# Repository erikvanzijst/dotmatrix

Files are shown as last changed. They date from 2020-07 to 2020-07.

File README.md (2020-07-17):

16x16 Monochrome Dot Matrix Display
===================================

A project to design and create a custom LED matrix display.

Full writeup and details at: https://medium.com/@erikvanzijst/custom-16x16-matrix-display-pcb-96c40290c8bc

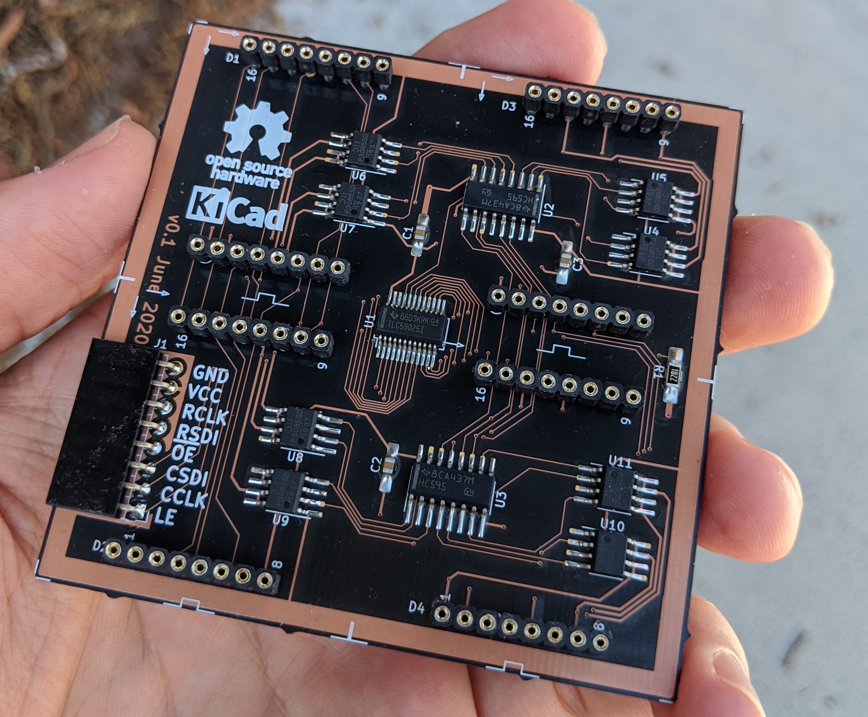
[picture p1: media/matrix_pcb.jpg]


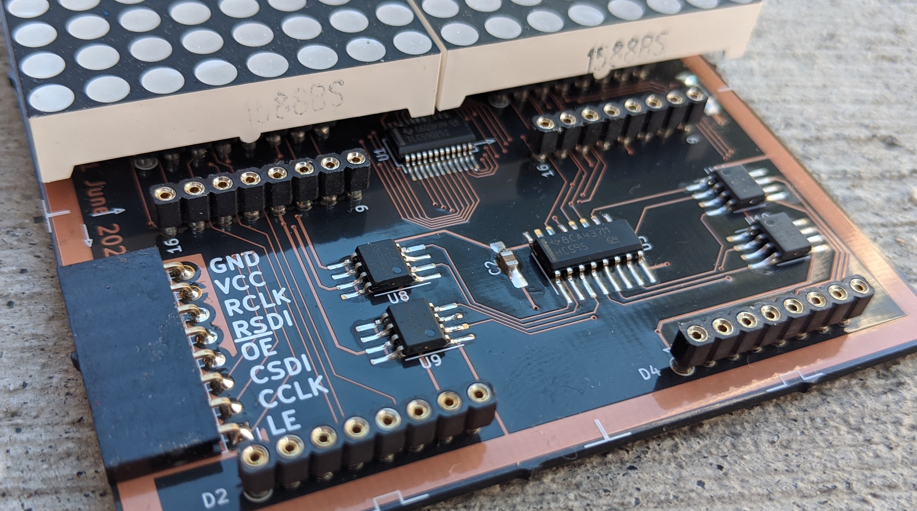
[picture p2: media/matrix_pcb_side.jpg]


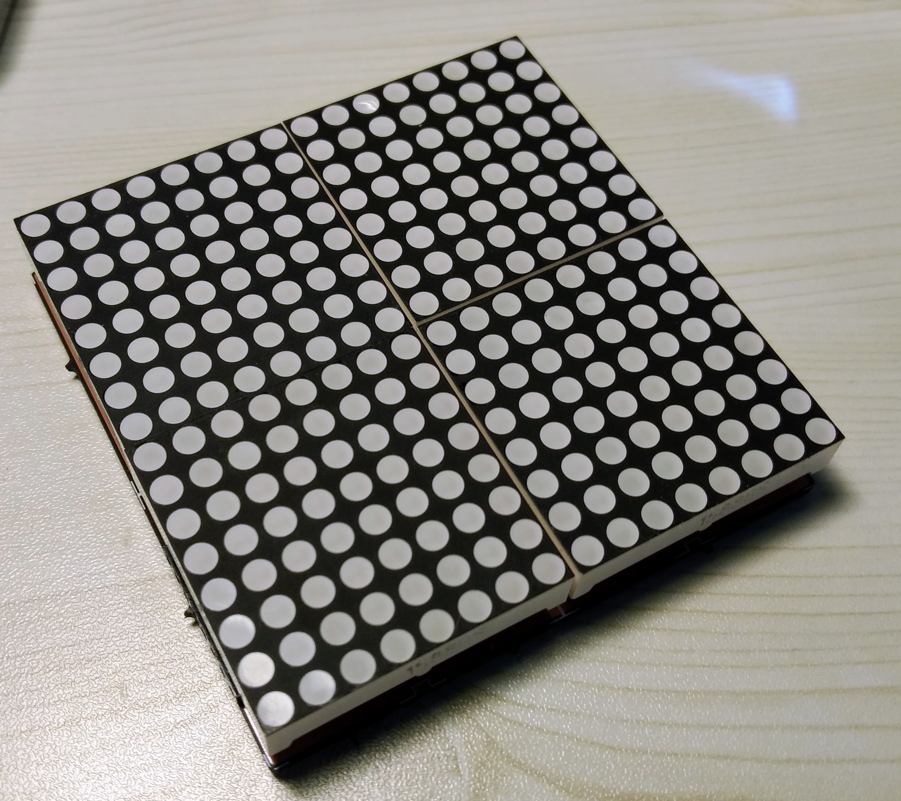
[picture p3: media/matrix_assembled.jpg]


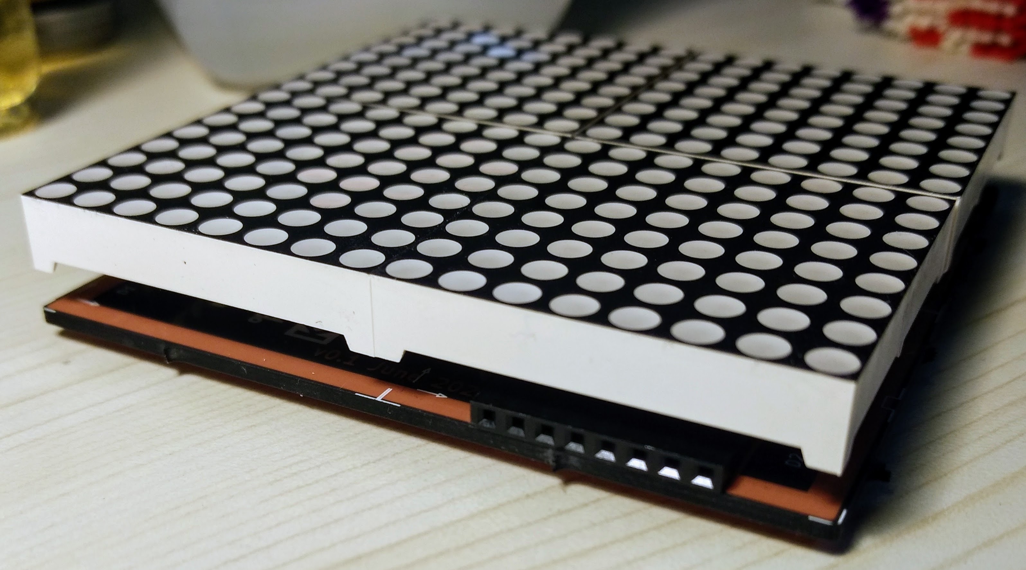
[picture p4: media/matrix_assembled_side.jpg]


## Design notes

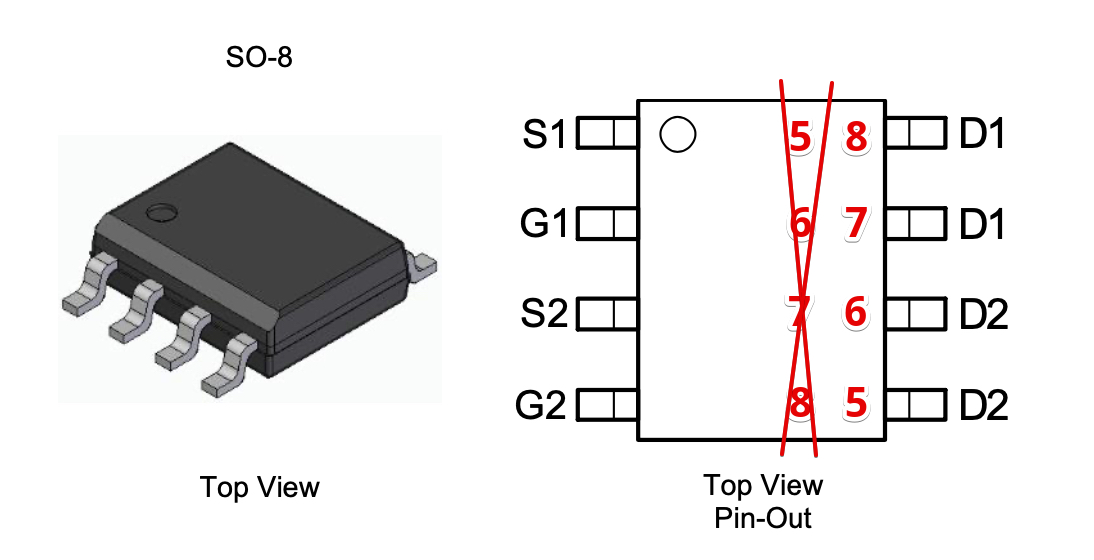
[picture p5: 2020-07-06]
media/mosfet_pinout_fail.jpg

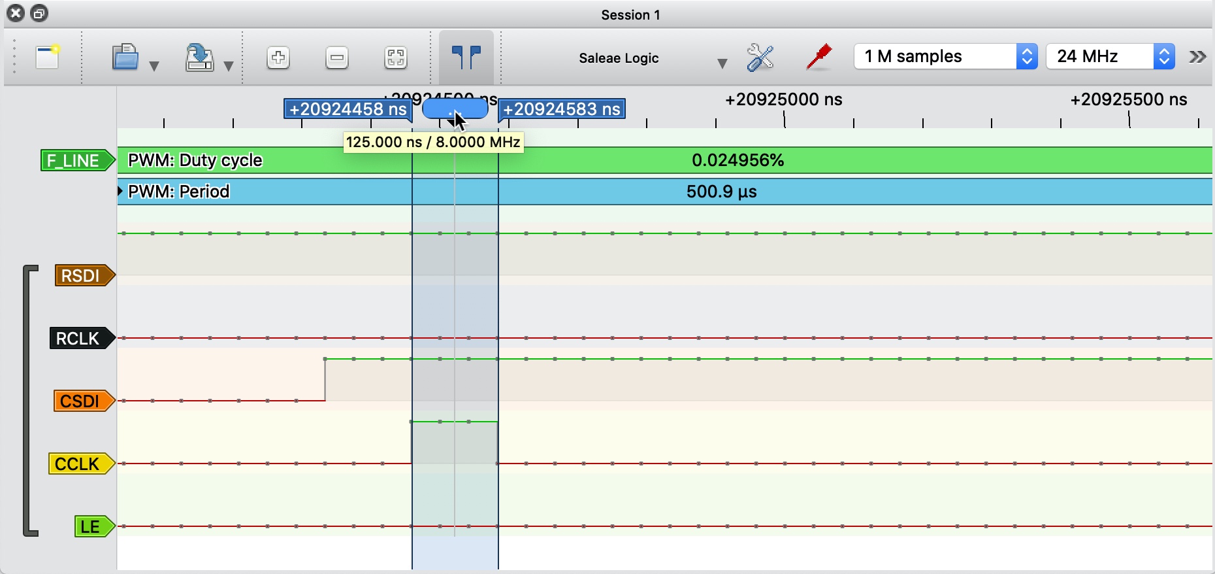
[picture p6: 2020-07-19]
media/pulseview_fastgpio2.jpg

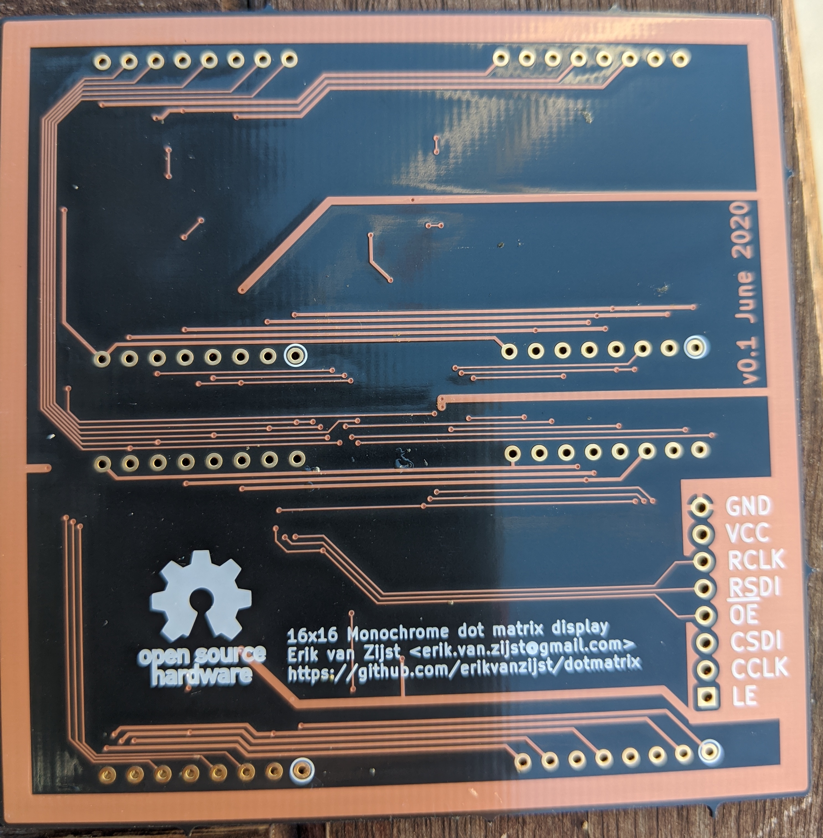
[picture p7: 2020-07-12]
media/pcb_back.jpg

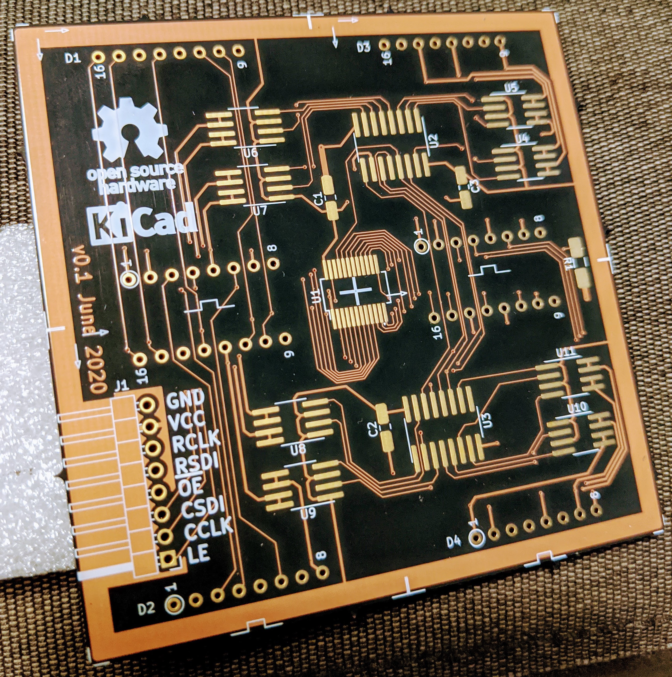
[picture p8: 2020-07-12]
media/pcb2.jpg

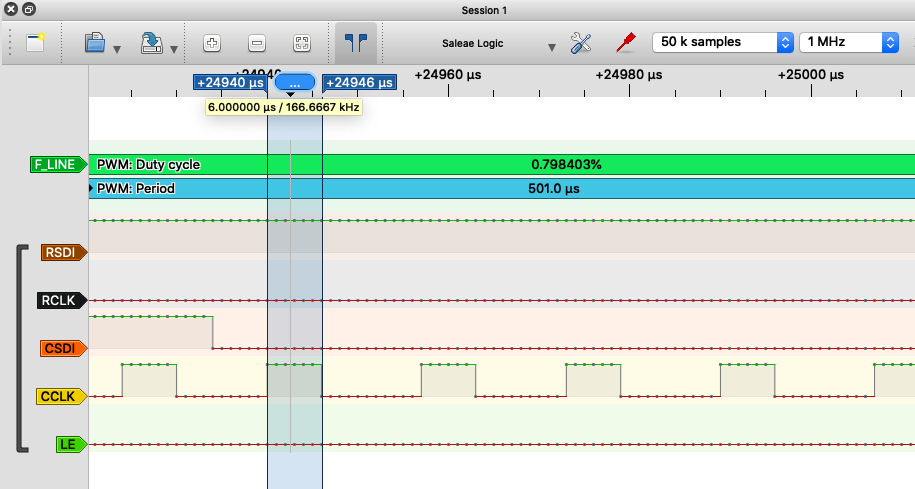
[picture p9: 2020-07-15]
media/pulse_6us.jpg

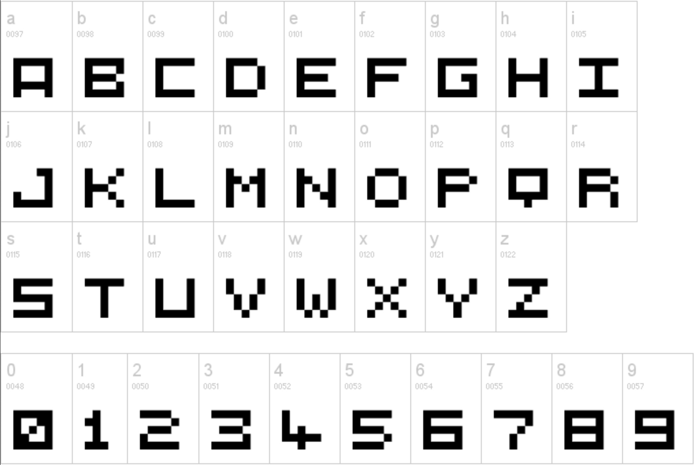
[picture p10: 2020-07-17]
media/5x5font.jpg

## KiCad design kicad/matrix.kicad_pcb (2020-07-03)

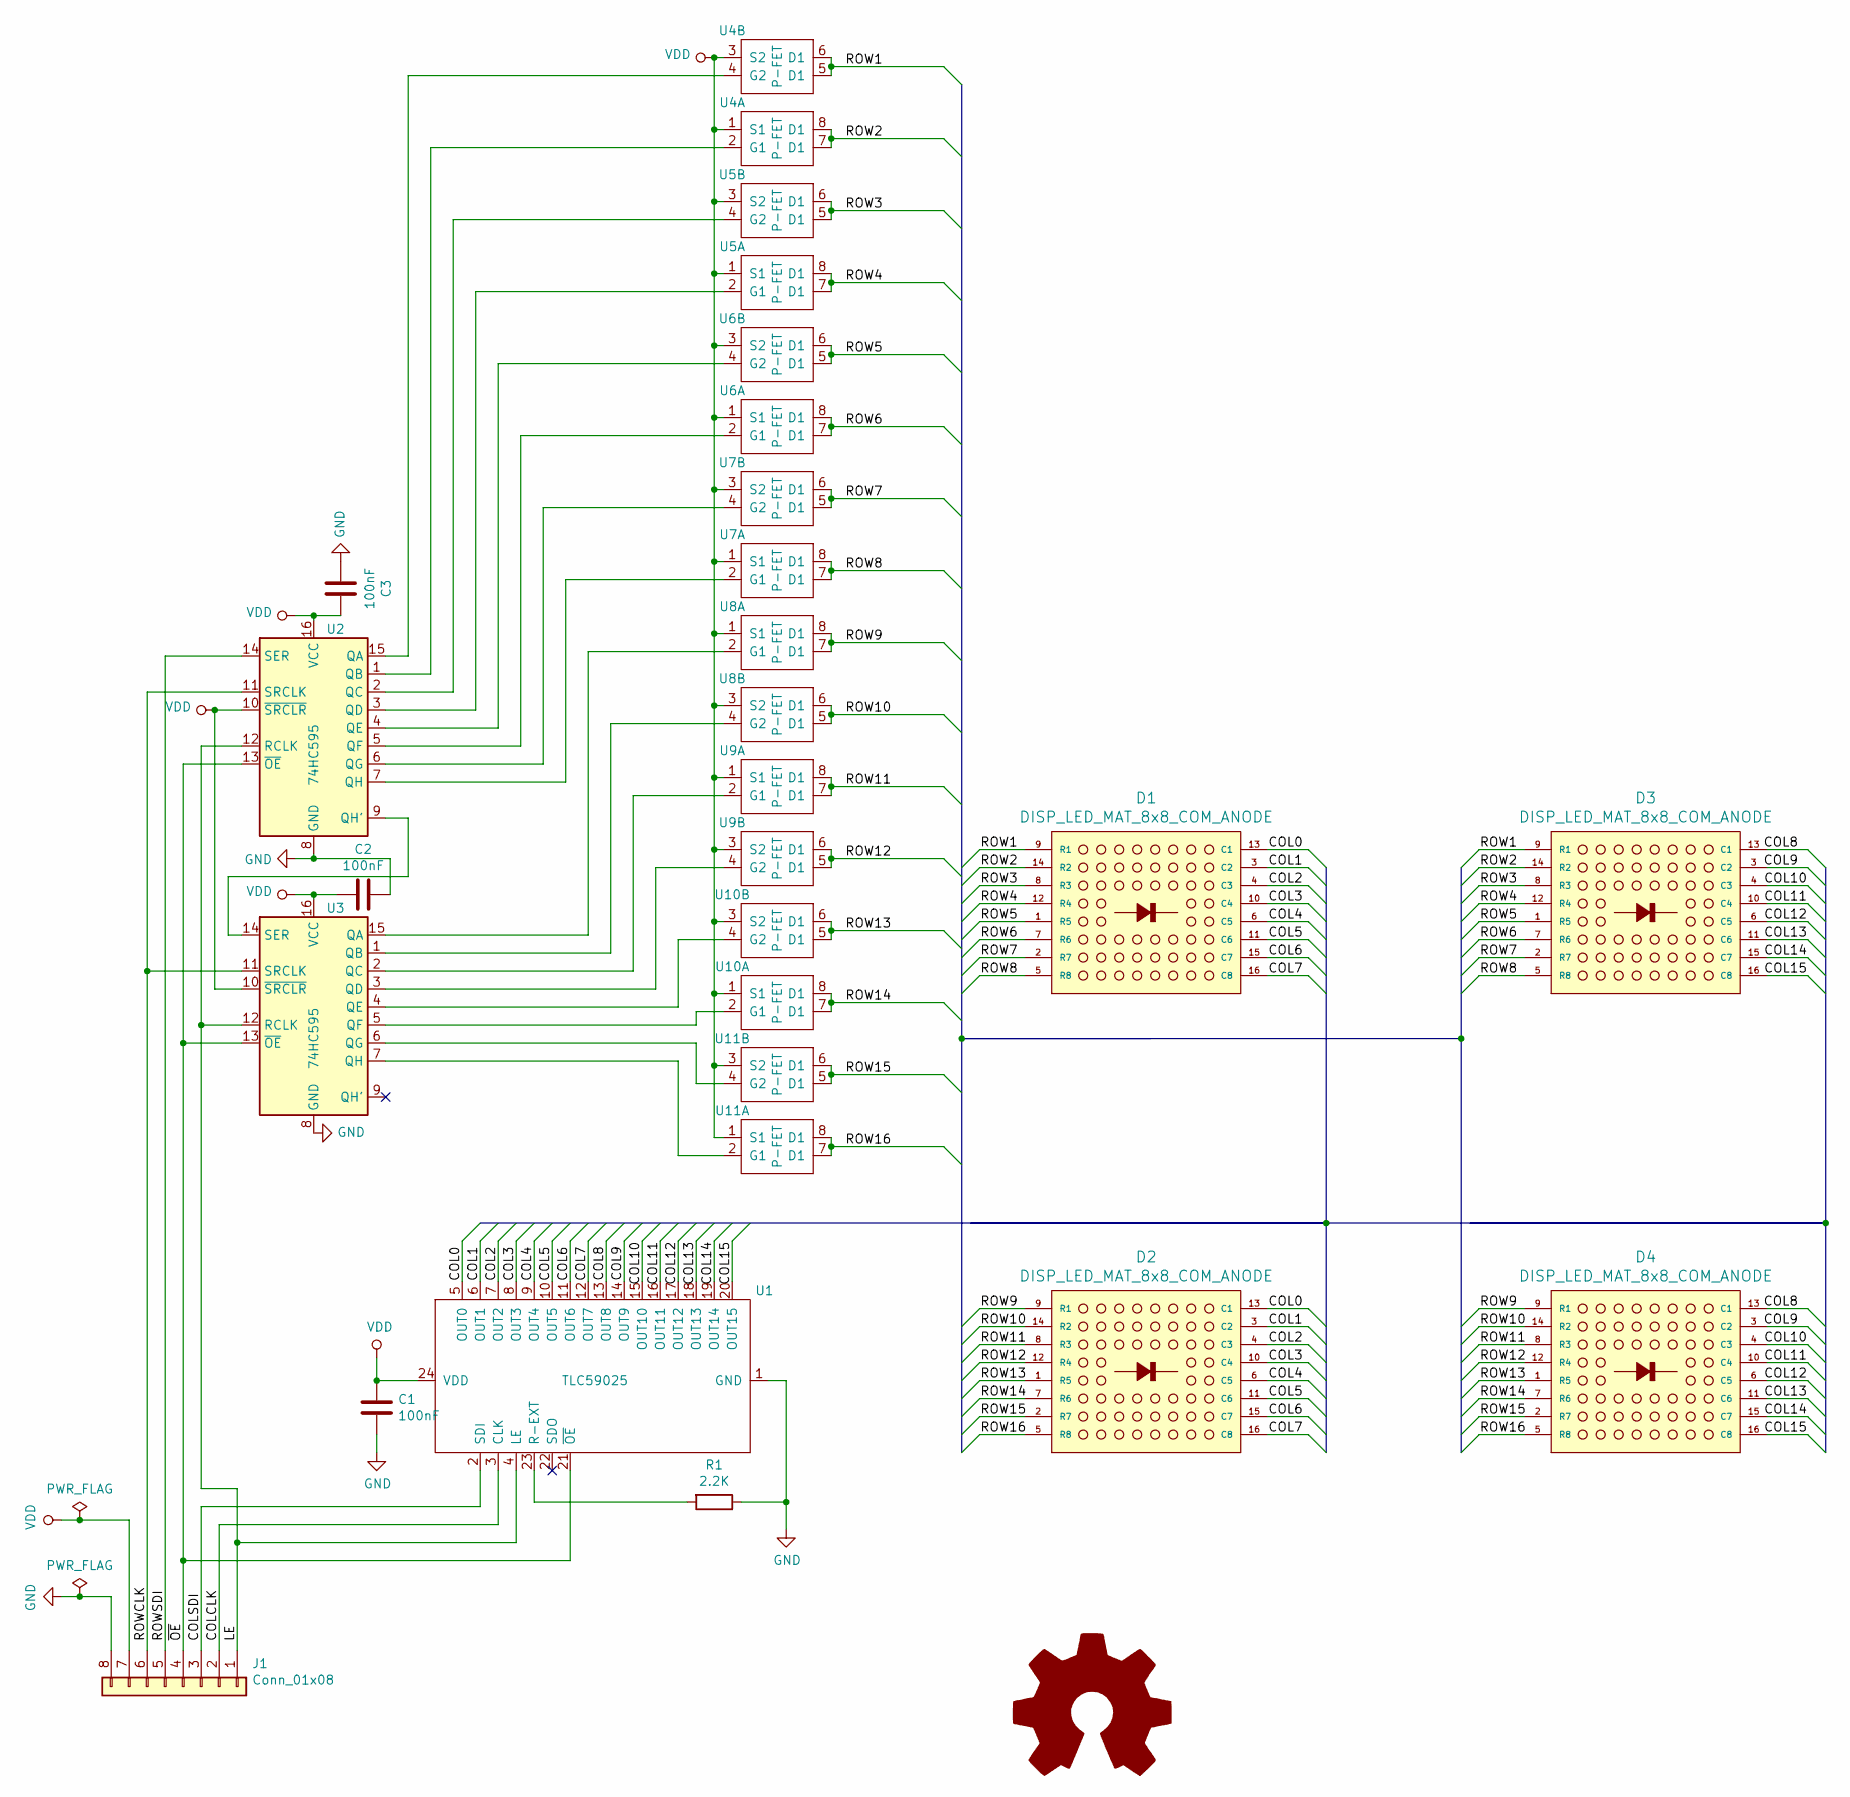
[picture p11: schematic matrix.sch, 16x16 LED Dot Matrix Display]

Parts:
C1, C2, C3: 100nF; C_0805_2012Metric_Pad1.15x1.40mm_widepads
D1, D2, D3, D4: DISP_LED_MAT_8x8_COM_ANODE; LED_8x8_3MM_38x38MM
J1: Conn_01x08; PinHeader_1x08_P2.54mm_Horizontal
R1: 2.2K; R_1206_3216Metric_Pad1.42x1.75mm_widepads
U1: TLC59025; SSOP-24_3.9x8.7mm_P0.635mm_widepads
U2, U3: 74HC595; SOIC-16_3.9x9.9mm_P1.27mm_widepads
U4, U5, U6, U7, U8, U9, U10, U11: P-FET; SOIC-8_3.9x4.9mm_P1.27mm_widepads

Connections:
/COL0: D1.13 (C1), D2.13 (C1), U1.5 (OUT0)
/COL1: D1.3 (C2), D2.3 (C2), U1.6 (OUT1)
/COL2: D1.4 (C3), D2.4 (C3), U1.7 (OUT2)
/COL3: D1.10 (C4), D2.10 (C4), U1.8 (OUT3)
/COL4: D1.6 (C5), D2.6 (C5), U1.9 (OUT4)
/COL5: D1.11 (C6), D2.11 (C6), U1.10 (OUT5)
/COL6: D1.15 (C7), D2.15 (C7), U1.11 (OUT6)
/COL7: D1.16 (C8), D2.16 (C8), U1.12 (OUT7)
/COL8: D3.13 (C1), D4.13 (C1), U1.13 (OUT8)
/COL9: D3.3 (C2), D4.3 (C2), U1.14 (OUT9)
/COL10: D3.4 (C3), D4.4 (C3), U1.15 (OUT10)
/COL11: D3.10 (C4), D4.10 (C4), U1.16 (OUT11)
/COL12: D3.6 (C5), D4.6 (C5), U1.17 (OUT12)
/COL13: D3.11 (C6), D4.11 (C6), U1.18 (OUT13)
/COL14: D3.15 (C7), D4.15 (C7), U1.19 (OUT14)
/COL15: D3.16 (C8), D4.16 (C8), U1.20 (OUT15)
/COLCLK: J1.2, U1.3 (CLK)
/COLSDI: J1.3, U1.2 (SDI)
/LE: J1.1, U1.4 (LE), U2.12 (RCLK), U3.12 (RCLK)
/ROW1: D1.9 (R1), D3.9 (R1), U4.5 (D1), U4.6 (D1)
/ROW2: D1.14 (R2), D3.14 (R2), U4.7 (D1), U4.8 (D1)
/ROW3: D1.8 (R3), D3.8 (R3), U5.5 (D1), U5.6 (D1)
/ROW4: D1.12 (R4), D3.12 (R4), U5.7 (D1), U5.8 (D1)
/ROW5: D1.1 (R5), D3.1 (R5), U6.5 (D1), U6.6 (D1)
/ROW6: D1.7 (R6), D3.7 (R6), U6.7 (D1), U6.8 (D1)
/ROW7: D1.2 (R7), D3.2 (R7), U7.5 (D1), U7.6 (D1)
/ROW8: D1.5 (R8), D3.5 (R8), U7.7 (D1), U7.8 (D1)
/ROW9: D2.9 (R1), D4.9 (R1), U8.7 (D1), U8.8 (D1)
/ROW10: D2.14 (R2), D4.14 (R2), U8.5 (D1), U8.6 (D1)
/ROW11: D2.8 (R3), D4.8 (R3), U9.7 (D1), U9.8 (D1)
/ROW12: D2.12 (R4), D4.12 (R4), U9.5 (D1), U9.6 (D1)
/ROW13: D2.1 (R5), D4.1 (R5), U10.5 (D1), U10.6 (D1)
/ROW14: D2.7 (R6), D4.7 (R6), U10.7 (D1), U10.8 (D1)
/ROW15: D2.2 (R7), D4.2 (R7), U11.5 (D1), U11.6 (D1)
/ROW16: D2.5 (R8), D4.5 (R8), U11.7 (D1), U11.8 (D1)
/ROWCLK: J1.6, U2.11 (SRCLK), U3.11 (SRCLK)
/ROWSDI: J1.5, U2.14 (SER)
/~OE: J1.4, U1.21 (~OE), U2.13 (~OE), U3.13 (~OE)
GND: C1.2, C2.1, C3.2, J1.8, R1.1, U1.1 (GND), U2.8 (GND), U3.8 (GND)
unnamed: R1.2, U1.23 (R-EXT)
unnamed: U2.1 (QB), U4.2 (G1)
unnamed: U2.2 (QC), U5.4 (G2)
unnamed: U2.3 (QD), U5.2 (G1)
unnamed: U2.4 (QE), U6.4 (G2)
unnamed: U2.5 (QF), U6.2 (G1)
unnamed: U2.6 (QG), U7.4 (G2)
unnamed: U2.7 (QH), U7.2 (G1)
unnamed: U2.9 (QH'), U3.14 (SER)
unnamed: U2.15 (QA), U4.4 (G2)
unnamed: U3.1 (QB), U8.4 (G2)
unnamed: U3.2 (QC), U9.2 (G1)
unnamed: U3.3 (QD), U9.4 (G2)
unnamed: U3.15 (QA), U8.2 (G1)
unnamed: U3.5 (QF), U10.2 (G1)
unnamed: U3.4 (QE), U10.4 (G2)
unnamed: U3.7 (QH), U11.2 (G1)
unnamed: U3.6 (QG), U11.4 (G2)
VDD: C1.1, C2.2, C3.1, J1.7, U1.24 (VDD), U2.10 (~SRCLR), U2.16 (VCC), U3.10 (~SRCLR), U3.16 (VCC), U4.1 (S1), U4.3 (S2), U5.1 (S1), U5.3 (S2), U6.1 (S1), U6.3 (S2), U7.1 (S1), U7.3 (S2), U8.1 (S1), U8.3 (S2), U9.1 (S1), U9.3 (S2), U10.1 (S1), U10.3 (S2), U11.1 (S1), U11.3 (S2)

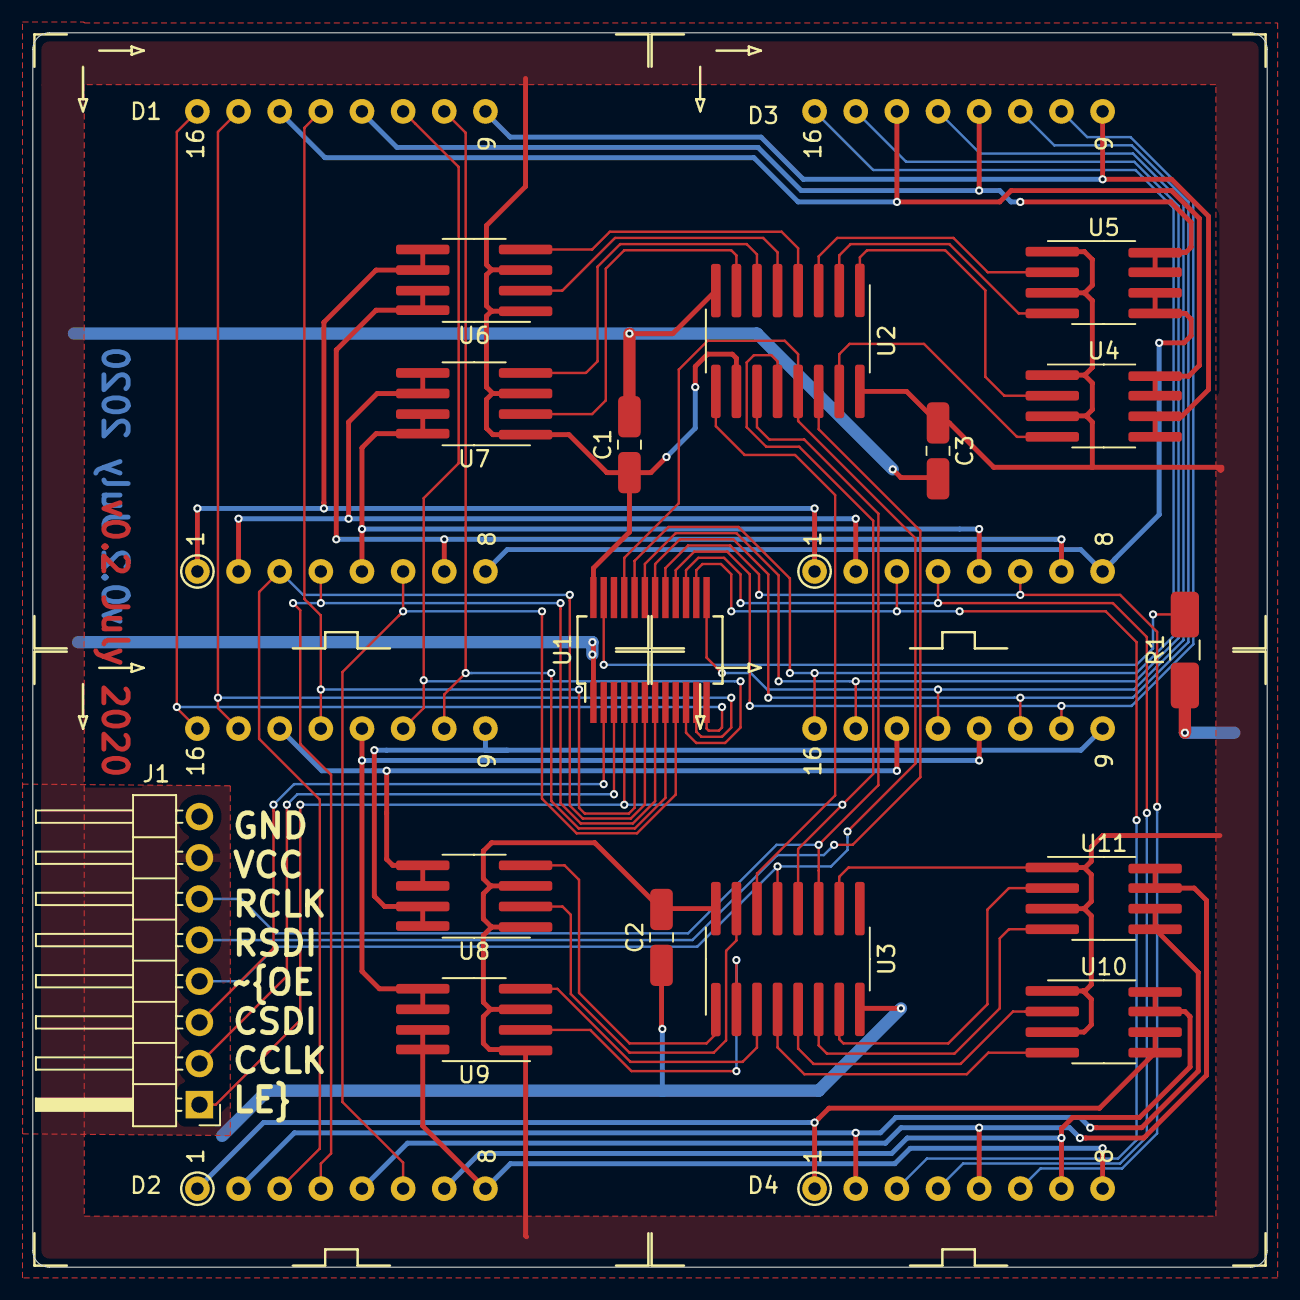
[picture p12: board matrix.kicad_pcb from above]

Board: 2 copper layers, 76.2 x 76.2 mm, 20 parts (0 on the bottom side), 58 nets.

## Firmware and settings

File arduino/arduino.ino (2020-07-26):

/*
Copyright (c) 2020 Erik van Zijst <erik.van.zijst@gmail.com>

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
THE SOFTWARE IS PROVIDED "AS IS", WITHOUT WARRANTY OF ANY KIND, EXPRESS OR
IMPLIED, INCLUDING BUT NOT LIMITED TO THE WARRANTIES OF MERCHANTABILITY,
FITNESS FOR A PARTICULAR PURPOSE AND NONINFRINGEMENT. IN NO EVENT SHALL THE
AUTHORS OR COPYRIGHT HOLDERS BE LIABLE FOR ANY CLAIM, DAMAGES OR OTHER
LIABILITY, WHETHER IN AN ACTION OF CONTRACT, TORT OR OTHERWISE, ARISING FROM,
OUT OF OR IN CONNECTION WITH THE SOFTWARE OR THE USE OR OTHER DEALINGS IN THE
SOFTWARE.
*/
#include <EEPROM.h>
#include <FastGPIO.h>

// Display driver
const unsigned DIM        = 16;
const unsigned width      = DIM * DIM;

const unsigned int RCLK   = 7;
const unsigned int RSDI   = 6;
const unsigned int OE     = 5;
const unsigned int CSDI   = 4;
const unsigned int CCLK   = 3;
const unsigned int LE     = 2;

volatile unsigned int screen[DIM];
volatile byte row = 0;

typedef struct {
  const unsigned int pin;
  int currState;  // the current reading from the input pin
  int lastState;  // the previous reading from the input pin
  unsigned long lastChanged;
  unsigned long lastDebounce;
} Button;

Button LEFT   = {A0, LOW, LOW, 0, 0};
Button RIGHT  = {A2, LOW, LOW, 0, 0};
Button ROT    = {A3, LOW, LOW, 0, 0};
Button DOWN   = {A1, LOW, LOW, 0, 0};
Button PAUSE  = {A4, LOW, LOW, 0, 0};
const unsigned long debounceDelay = 50;

typedef struct {
  int x, y;
} Vertex;

typedef struct {
  Vertex vertex[4];
} Shape;

typedef struct {
  Shape shape[4];
} BrickDef;

BrickDef brickdefs[7] = {
  { // I
    .shape = {
      { .vertex = {{-1, 0}, {0, 0}, {1, 0}, {2, 0}} },
      { .vertex = {{0, 1}, {0, 0}, {0, -1}, {0, -2}} },
      { .vertex = {{-1, 0}, {0, 0}, {1, 0}, {2, 0}} },
      { .vertex = {{0, 1}, {0, 0}, {0, -1}, {0, -2}} }
    }
  },
  { // O
    .shape = {
      { .vertex = {{0, 0}, {0, 1}, {1, 0}, {1, 1}} },
      { .vertex = {{0, 0}, {0, 1}, {1, 0}, {1, 1}} },
      { .vertex = {{0, 0}, {0, 1}, {1, 0}, {1, 1}} },
      { .vertex = {{0, 0}, {0, 1}, {1, 0}, {1, 1}} }
    }
  },
  { // J
    .shape = {
      { .vertex = {{0, 0}, {1, 0}, {2, 0}, {2, 1}} },
      { .vertex = {{1, 1}, {1, 0}, {1, -1}, {0, 1}} },
      { .vertex = {{0, -1}, {0, 0}, {1, 0}, {2, 0}} },
      { .vertex = {{1, -1}, {1, 0}, {1, 1}, {2, -1}} }
    }
  },
  { // L
    .shape = {
      { .vertex = {{0, 1}, {0, 0}, {1, 0}, {2, 0}} },
      { .vertex = {{0, -1}, {1, -1}, {1, 0}, {1, 1}} },
      { .vertex = {{0, 0}, {1, 0}, {2, 0}, {2, -1}} },
      { .vertex = {{1, -1}, {1, 0}, {1, 1}, {2, 1}} }
    }
  },
  { // S
    .shape = {
      { .vertex = {{0, 1}, {1, 1}, {1, 0}, {2, 0}} },
      { .vertex = {{1, -1}, {1, 0}, {2, 0}, {2, 1}} },
      { .vertex = {{0, 1}, {1, 1}, {1, 0}, {2, 0}} },
      { .vertex = {{1, -1}, {1, 0}, {2, 0}, {2, 1}} }
    }
  },
  { // Z
    .shape = {
      { .vertex = {{0, 0}, {1, 0}, {1, 1}, {2, 1}} },
      { .vertex = {{1, -1}, {1, 0}, {0, 0}, {0, 1}} },
      { .vertex = {{0, 0}, {1, 0}, {1, 1}, {2, 1}} },
      { .vertex = {{1, -1}, {1, 0}, {0, 0}, {0, 1}} }
    }
  },
  { // T
    .shape = {
      { .vertex = {{0, 0}, {1, 0}, {2, 0}, {1, 1}} },
      { .vertex = {{1, -1}, {1, 0}, {1, 1}, {0, 0}} },
      { .vertex = {{0, 0}, {1, 0}, {2, 0}, {1, -1}} },
      { .vertex = {{1, -1}, {1, 0}, {1, 1}, {2, 0}} }
    }
  }
};

typedef struct {
  byte id;
  byte rotation;
  Vertex location;
} FallingBrick;

const byte WIDTH = 10;  // width of tetris board

// partial minimalist 5x5 font from https://www.dafont.com/5x5.font
const byte font[43][5] PROGMEM = {
  {0x1f, 0x13, 0x15, 0x19, 0x1f}, // 0
  {0x04, 0x0c, 0x04, 0x04, 0x0e}, // 1
  {0x1e, 0x01, 0x0e, 0x10, 0x1f}, // 2
  {0x1f, 0x01, 0x0e, 0x01, 0x1f}, // 3
  {0x10, 0x10, 0x14, 0x1f, 0x04}, // 4
  {0x1f, 0x10, 0x1e, 0x01, 0x1e}, // 5
  {0x1f, 0x10, 0x1f, 0x11, 0x1f}, // 6
  {0x1f, 0x01, 0x02, 0x04, 0x04}, // 7
  {0x1f, 0x11, 0x1f, 0x11, 0x1f}, // 8
  {0x1f, 0x11, 0x1f, 0x01, 0x1f}, // 9

  {0x0, 0x04, 0x0, 0x04, 0x0},    // :
  {0x0, 0x04, 0x0, 0x04, 0x04},   // ;
  {0, 0, 0, 0, 0},  // <
  {0, 0, 0, 0, 0},  // =
  {0, 0, 0, 0, 0},  // >
  {0, 0, 0, 0, 0},  // ?
  {0, 0, 0, 0, 0},  // fake space

  {0x1f, 0x11, 0x11, 0x1f, 0x11}, // A
  {0x1f, 0x11, 0x1e, 0x11, 0x1f}, // B
  {0x1f, 0x10, 0x10, 0x10, 0x1f}, // C
  {0x1e, 0x11, 0x11, 0x11, 0x1e}, // D
  {0x1f, 0x10, 0x1e, 0x10, 0x1f}, // E
  {0x1f, 0x10, 0x1e, 0x10, 0x10}, // F
  {0x1f, 0x10, 0x13, 0x11, 0x1f}, // G
  {0x11, 0x11, 0x1f, 0x11, 0x11}, // H
  {0x1f, 0x04, 0x04, 0x04, 0x1f}, // I
  {0x03, 0x01, 0x01, 0x11, 0x1f}, // J
  {0x11, 0x12, 0x1c, 0x12, 0x11}, // K
  {0x10, 0x10, 0x10, 0x10, 0x1f}, // L
  {0x11, 0x1b, 0x15, 0x11, 0x11}, // M
  {0x11, 0x19, 0x15, 0x13, 0x11}, // N
  {0x0e, 0x11, 0x11, 0x11, 0x0e}, // O
  {0x1e, 0x11, 0x1e, 0x10, 0x10}, // P
  {0x1f, 0x11, 0x11, 0x1f, 0x04}, // Q
  {0x1e, 0x11, 0x1e, 0x11, 0x11}, // R
  {0x1f, 0x10, 0x1f, 0x01, 0x1f}, // S
  {0x1f, 0x04, 0x04, 0x04, 0x04}, // T
  {0x11, 0x11, 0x11, 0x11, 0x1f}, // U
  {0x11, 0x11, 0x0a, 0x0a, 0x04}, // V
  {0x11, 0x11, 0x15, 0x15, 0x0a}, // W
  {0x11, 0x0a, 0x04, 0x0a, 0x11}, // X
  {0x11, 0x11, 0x0a, 0x04, 0x04}, // Y
  {0x1f, 0x02, 0x04, 0x08, 0x1f}  // Z
};

void setup() {
  cli();

  Serial.begin(115200);

  FastGPIO::Pin<RCLK>::setOutputLow();
  FastGPIO::Pin<RSDI>::setOutputLow();
  FastGPIO::Pin<OE>::setOutputLow();
  FastGPIO::Pin<CSDI>::setOutputLow();
  FastGPIO::Pin<CCLK>::setOutputLow();
  FastGPIO::Pin<LE>::setOutputLow();

  pinMode(LEFT.pin, INPUT);
  pinMode(RIGHT.pin, INPUT);
  pinMode(ROT.pin, INPUT);
  pinMode(DOWN.pin, INPUT);

  randomSeed(analogRead(A4)); // poor attempt at random data from floating input
  clearScreen();

  // Schedule timer interrupt to draw 1 display row at a time on
  // Timer2 at 2kHz yielding 125Hz refresh rate.
  //
  // The scanline ISR takes 296us, making 3kHz the absolute fastest we could
  // schedule the interrupt, as the display would consume the entire CPU with no
  // cycles left for the main program loop.
  // We need 16 scanlines for one full refresh, so for a robust flicker-free refresh
  // rate of 125Hz, we need a 2kHz interrupt timer, consuming about two thirds
  // of the ATmega328's processing power.

  TCCR2A = 0;               // set entire TCCR2A register to 0
  TCCR2B = 0;               // same for TCCR2B
  TCNT2  = 0;               // initialize counter value to 0

  // set compare match register for 2khz increments
  OCR2A = 124;              // = (16*10^6) / (2000*64) - 1 (must be <256)
  TCCR2A |= (1 << WGM21);   // turn on CTC mode
  TCCR2B |= (1 << CS22);    // Set CS22 bit for 64 prescaler
  TIMSK2 |= (1 << OCIE2A);  // enable timer compare interrupt

  sei();
}

void clearScreen() {
  for (byte row = 0; row < DIM; row++) {
    screen[row] = 0;
  }
}

SIGNAL(TIMER2_COMPA_vect) {
  FastGPIO::Pin<RSDI>::setOutputValue(row != 0);

  FastGPIO::Pin<RCLK>::setOutputValueHigh();
  FastGPIO::Pin<RCLK>::setOutputValueLow();

  for (unsigned int col = 1; col; col <<= 1) {
    FastGPIO::Pin<CSDI>::setOutputValue((screen[row] & col) ? HIGH : LOW);

    FastGPIO::Pin<CCLK>::setOutputValueHigh();
    FastGPIO::Pin<CCLK>::setOutputValueLow();
  }

  FastGPIO::Pin<LE>::setOutputValueHigh();
  FastGPIO::Pin<LE>::setOutputValueLow();
  row = (row + 1) % DIM;
}

// Adjust for hardware wiring error in v01:
// https://github.com/erikvanzijst/dotmatrix/commit/3c7690eb47
#define fix(row) (row + ((row & 1) ? -1 : 1))

void setpixel(unsigned int row, unsigned int col, bool on) {
  if (on) {
    screen[fix(row)] |= (0x8000 >> col);
  } else {
    screen[fix(row)] &= ((0x8000 >> col) ^ 0xff);
  }
}

/*
 * Returns true if the button went from not pressed to pressed.
 */
bool waspressed(Button *button) {
  const int value = digitalRead(button->pin);
  if (value != button->lastState) {
    button->lastDebounce = millis();
    button->lastState = value;
  }

  if ((millis() - button->lastDebounce) > debounceDelay && value != button->currState) {
    button->currState = value;
    button->lastChanged = millis();
    if (button->currState == HIGH) {
      return true;
    }
  }
  return false;
}

bool islongpressed(Button *button) {
  return button->currState == HIGH && (millis() - button->lastChanged) >= 400;
}

/* Tetris */

void drawboard(unsigned int *board, FallingBrick *brick) {
  Shape shape;
  materialize(&shape, brick);
  for (byte i = 0; i < DIM; i++) {
    screen[fix(i)] &= 0x801F; // clear the board section of the screen line
    screen[fix(i)] |= ((board[i] >> 1) & 0x7fe0);
  }
  for (byte i = 0; i < 4; i++) {
    setpixel(shape.vertex[i].y, shape.vertex[i].x + 1, true);
  }
}

void drawnext(byte id) {
  // clear preview area:
  for (byte row = 0; row < 5; row++) {
    screen[fix(row)] &= 0xfff0;
  }
  // paint the next tetromino:
  for (byte i = 0; i < 4; i++) {
    setpixel(brickdefs[id].shape[0].vertex[i].y + 2, brickdefs[id].shape[0].vertex[i].x + 13, true);
  }
}

bool fits(FallingBrick *brick, unsigned int *board) {
  Shape shape;
  materialize(&shape, brick);

  for (byte i = 0; i < 4; i++) {
    if (shape.vertex[i].y < 0 || shape.vertex[i].y >= DIM || shape.vertex[i].x < 0 || shape.vertex[i].x >= WIDTH ||
        (board[shape.vertex[i].y] & (0x8000 >> shape.vertex[i].x))) {
      return false;
    }
  }
  return true;
}

void materialize(Shape *dest, FallingBrick *brick) {
  for (byte i = 0; i < 4; i++) {
    dest->vertex[i].x = brickdefs[brick->id].shape[brick->rotation].vertex[i].x + brick->location.x;
    dest->vertex[i].y = brickdefs[brick->id].shape[brick->rotation].vertex[i].y + brick->location.y;
  }
}

bool move(FallingBrick *dest, FallingBrick *src, int rot, Vertex *vector, unsigned int *board) {
  memcpy(dest, src, sizeof(FallingBrick));

  dest->rotation = (dest->rotation + rot) % 4;
  dest->location.x += vector->x;
  dest->location.y += vector->y;

  return fits(dest, board);
}

void printBrick(FallingBrick *brick) {
  Shape shape;
  materialize(&shape, brick);
  Serial.print(F("Shape: "));
  for (int i = 0; i < 4; i++) {
    Serial.print(F("("));
    Serial.print(shape.vertex[i].x, DEC);
    Serial.print(F(", "));
    Serial.print(shape.vertex[i].y, DEC);
    Serial.print(F(") "));
  }
  Serial.println(brick->rotation);
}

byte merge(FallingBrick *brick, unsigned int *board) {
  byte removed = 0;
  Shape shape;
  materialize(&shape, brick);
  for (byte i = 0; i < 4; i++) {
    board[shape.vertex[i].y] |= (0x8000 >> shape.vertex[i].x);
  }

  // remove completed lines:
  int row = DIM - 1;
  for (int i = DIM - 1; i >= 0; i--) {
    if (board[i] < 0xffc0) {
      board[row--] = board[i];
    } else {
      removed++;
    }
  }
  for (; row >= 0; row--) {
    board[row] = 0;
  }
  return removed;
}

int toGlyphs(byte *glyphs, const char *str) {
  for (unsigned int i = 0; i < strlen(str); i++) {
    const int j = ((int)str[i]) == 0x20 ? 0x10 : ((int)toupper(str[i])) - 0x30; // space is mapped to @
    if (j < 0 || j > 43) {
      Serial.print("Invalid character! 0x");
      Serial.println((int)str[i], HEX);
      return -1;
    }
    memcpy_P(glyphs + i*5, &(font[j]), 5);
  }
  return 0;
}

void scroll(const char *line1, const char *line2, long timeout) {
  const unsigned long start = millis();
  struct Line {
    unsigned int pos = 0;
    byte row;
    byte *glyphs;
    unsigned int len;
  };
  Line lines[2];
  byte glyphs1[strlen(line1) * 5];
  byte glyphs2[strlen(line2) * 5];

  if (toGlyphs((byte *)glyphs1, line1) || toGlyphs((byte *)glyphs2, line2)) {
    return;
  }
  lines[0].row = strlen(line2) == 0 ? 5 : 2;
  lines[0].glyphs = glyphs1;
  lines[0].len = strlen(line1);
  lines[1].row = strlen(line1) == 0 ? 5 : 10;
  lines[1].glyphs = glyphs2;
  lines[1].len = strlen(line2);

  while ((timeout == -1 || (millis() - start) < timeout) && !waspressed(&ROT) && !waspressed(&PAUSE)) {
    for (byte i = 0; i < 2; i++) {
      for (int r = 4; lines[i].len && r >= 0; r--) {
        screen[fix(lines[i].row + r)] <<= 1;
        screen[fix(lines[i].row + r)] |= (
          (*(lines[i].glyphs + ((lines[i].pos / 6) * 5) + r) & (0x20 >> (lines[i].pos % 6))) ? 1 : 0);
      }
      lines[i].pos = (lines[i].pos + 1) % (lines[i].len * 6);
    }
    delay(75);
  }
}

/*
 * Returns the speed associated with the specified number of removed lines.
 * Speed in measured in delay ms.
 */
unsigned int getspeed(unsigned int lines) {
  return (unsigned int) max((-5.6 * lines + 550) + 50, 50);
}

void pause() {
  if (waspressed(&PAUSE)) {
    unsigned int saved[DIM];

    Serial.println(F("Paused..."));
    memcpy(saved, screen, sizeof(screen));
    clearScreen();

    scroll(
      "Paused          ",
      "        Paused  ",
      -1);

    memcpy(screen, saved, sizeof(screen));
    Serial.println(F("Resuming..."));
  }
}

Vertex down = {0, 1};
Vertex left = {-1, 0};
Vertex right = {1, 0};
Vertex identity = {0, 0};
const unsigned int linevalue[] = {0, 40, 100, 300, 1200};

void loop() {
  clearScreen();
  scroll("TETRIS   ", "", 4000);

  unsigned int lines = 0;
  unsigned int score = 0;
  unsigned long speed = getspeed(lines);
  unsigned long now = millis();
  unsigned int board[DIM];
  memset(board, 0, sizeof(unsigned int) * DIM);
  byte next = (byte)random(7);

  for (byte i = 0; i < DIM; i++) {
    screen[i] = 0x8010; // paint background
  }
  drawnext(next);

  FallingBrick brick = {
    .id = (byte)random(7),
    .rotation = 0,
    .location = {.x = 4, .y = 0}
  };
  FallingBrick copy;

  while (true) {
    pause();

    if (waspressed(&LEFT)) {
      if(move(&copy, &brick, 0, &left, board)) {
        memcpy(&brick, &copy, sizeof(FallingBrick));
        drawboard(board, &brick);
      }
    }
    if (waspressed(&RIGHT)) {
      if(move(&copy, &brick, 0, &right, board)) {
        memcpy(&brick, &copy, sizeof(FallingBrick));
        drawboard(board, &brick);
      }
    }
    if (waspressed(&ROT)) {
      if(move(&copy, &brick, 1, &identity, board)) {
        memcpy(&brick, &copy, sizeof(FallingBrick));
        drawboard(board, &brick);
      }
    }
    if (waspressed(&DOWN)) {
      now -= speed;
    } else if (islongpressed(&DOWN)) {
      speed = 40;
    } else {
      speed = getspeed(lines);
    }

    if ((millis() - now) > speed) {
      now = millis();

      if (move(&copy, &brick, 0, &down, board)) {
        memcpy(&brick, &copy, sizeof(FallingBrick));
      } else {
        Serial.println(F("Could not move down; merging."));
        printBrick(&brick);
        const byte removed = merge(&brick, board);
        lines += removed;
        score += linevalue[min(removed, 4)] + 1;

        brick.id = next;
        brick.rotation = 0;
        brick.location.x = 4;
        brick.location.y = 0;
        next = (int)random(7);
        drawnext(next);

        if (!move(&copy, &brick, 0, &down, board)) {
          gameover(score);
          return;
        }
      }
      drawboard(board, &brick);
    }
  }
}

void gameover(unsigned int score) {
  char top[]    = "YOU :             ";
  char bottom[] = "BEST:             ";
  const unsigned int hiscore = getAndSetHiscore(score);

  delay(1000);
  clearScreen();

  itoa(hiscore, (char *)(bottom + 5), 10);
  strcpy((char *)(bottom + strlen(bottom)), "  ");

  itoa(score, (char *)(top + 5), 10);
  memset((char *)(top + strlen(top)), 0x20, sizeof(top) - strlen(top));
  top[strlen(bottom)] = 0;

  waspressed(&ROT); // clear button state
  scroll(top, bottom, -1);
}

unsigned long getAndSetHiscore(unsigned long score) {
  const unsigned int FINGERPRINT = 54665;
  struct Hiscore {
    unsigned int fingerprint;
    unsigned long score;
  };
  Hiscore hiscore;

  EEPROM.get(0, hiscore);
  if (hiscore.fingerprint != FINGERPRINT || hiscore.score < score) {
    hiscore.fingerprint = FINGERPRINT;
    hiscore.score = score;
    EEPROM.put(0, hiscore);
  }
  return hiscore.score;
}

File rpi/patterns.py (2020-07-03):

#!/usr/bin/env python3
import argparse
from itertools import cycle, islice
from time import sleep
from typing import List, Iterator

from driver import MatrixDriver


def blank(args, dim: int = MatrixDriver.DIM) -> Iterator[List[int]]:
    while True:
        yield [(2 ** dim) - 1] * dim


def chess(args, dim: int = MatrixDriver.DIM) -> Iterator[List[int]]:
    """Generates a chessboard pattern with each consecutive pattern the inverse of the previous."""
    for j in cycle((0, 1)):
        yield [int(''.join(islice(cycle(('0', '1') if (i + j) % 2 else ('1', '0')), dim)), 2) for i in range(dim)]


def scan(args, dim: int = MatrixDriver.DIM) -> Iterator[List[int]]:
    """Generates a sequence of baords with one pixel lit. The pixel moves,
    following the horizontal scan lines, moving from the top-left to
    bottom-right one row at a time.
    """
    i = 0
    while True:
        g = ('1' if j == i else '0' for j in range(0, dim ** 2))
        yield [int(''.join(islice(g, dim)), 2) for _ in range(dim)]
        i = (i + 1) % (dim ** 2)


def allpatterns(args, dim: int = MatrixDriver.DIM) -> Iterator[List[int]]:
    raise AssertionError('Not implemented')


def main():
    patterns = {
        'blank': blank,
        'chess': chess,
        'scan': scan,
        'all': allpatterns
    }

    parser = argparse.ArgumentParser(description='Test dot matrix display.')
    parser.add_argument('pattern', help='the pattern to show', choices=list(patterns) + ['all'], nargs=1)
    parser.add_argument('-i', '--interval', help='time in seconds between patterns', default=1)
    args = parser.parse_args()

    display = MatrixDriver(1, 2, 3, 4, 5, 6, showhz=True)

    try:
        while True:
            for p in patterns[args.pattern[0]](args, display.DIM):
                display.draw(p)
                sleep(args.interval)
    except KeyboardInterrupt:
        pass
    finally:
        display.close()


if __name__ == '__main__':
    main()

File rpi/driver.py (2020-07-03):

from ctypes import c_bool, c_uint16
from time import time
from multiprocessing import Process, Value, Array
from typing import List

from gpiozero import DigitalOutputDevice


def _pulse(dev: DigitalOutputDevice) -> None:
    dev.pin.state = False
    dev.pin.state = True


def _run(screen: Array, die: Value, rowclk: int, rowsdi: int, oe: int, colsdi: int, colclk: int, le: int,
         showhz: bool):
    print("Connecting to display...")
    ROWSDI = DigitalOutputDevice(rowsdi)
    ROWCLK = DigitalOutputDevice(rowclk)
    COLSDI = DigitalOutputDevice(colsdi)
    COLCLK = DigitalOutputDevice(colclk)
    OE = DigitalOutputDevice(oe, initial_value=True)
    LE = DigitalOutputDevice(le)

    try:
        OE.pin.state = False
        cnt, last = 0, time()
        width = 2 ** MatrixDriver.DIM

        while not die.value:
            for row in range(MatrixDriver.DIM):
                LE.pin.state = False
                ROWSDI.pin.state = row != 0
                _pulse(ROWCLK)

                bit = 1
                value = screen[row]
                while bit < width:
                    COLSDI.pin.state = bool(value & bit)
                    _pulse(COLCLK)
                    bit <<= 1
                _pulse(LE)

            if showhz:
                cnt += 1
                now = time()
                if now - last > .5:
                    print("Refresh rate: %.1fHz" % (cnt / (now - last)))
                    cnt, last = 0, now
    finally:
        print("Releasing display...")
        ROWSDI.close()
        ROWCLK.close()
        COLSDI.close()
        COLCLK.close()
        LE.close()
        OE.close()


class MatrixDriver(object):
    DIM = 16

    def __init__(self, rowclk: int = 2, rowsdi: int = 3, oe: int = 4, colsdi: int = 17, colclk: int = 27, le: int = 22,
                 showhz: bool = False) -> None:
        self.screen = Array(c_uint16, [0] * self.DIM, lock=True)
        self.die = Value(c_bool, False)

        self.showhz = showhz
        self.process = Process(target=_run,
                               args=(self.screen, self.die, rowclk, rowsdi, oe, colsdi, colclk, le, showhz))
        self.process.start()

    def draw(self, screen: List[int]) -> None:
        assert len(screen) == self.DIM
        for i in range(self.DIM):
            self.screen[i] = screen[i]

    def setpixel(self, row: int, col: int, on: bool) -> None:
        if on:
            self.screen[row] |= (1 << col)
        else:
            self.screen[row] &= ((1 << col) ^ 0xff)

    def close(self) -> None:
        self.die.value = True
        self.process.join()

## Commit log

2020-06-01 Initial schematic for dot matrix display
    [matrix.kicad_pcb, matrix.sch]
2020-06-02 Add footprints and initial layout
    [matrix.kicad_pcb, matrix.sch]
2020-06-06 Add headers to schematic
    [matrix.sch]
2020-06-07 Add headers to PCB layout
    [matrix.kicad_pcb, matrix.sch]
2020-06-07 Add datasheets and long pad footprints
    [matrix.kicad_pcb, matrix.sch]
2020-06-07 Enlarge display footprint and SMD pad widths
    [matrix.kicad_pcb, matrix.sch]
2020-06-07 OshPark design rules and copper GND pour
    [matrix.kicad_pcb]
2020-06-07 Wire up cathodes
    [matrix.kicad_pcb]
2020-06-07 Switch to P-channel FETs in SOIC-8 package
    [matrix.kicad_pcb, matrix.sch]
2020-06-07 Add power net
    [matrix.kicad_pcb, matrix.sch]
2020-06-08 Finished most of the layout
    [matrix.kicad_pcb, matrix.sch]
2020-06-10 Scaled up 3d display models
    Also wired up the remaining nets.
    [matrix.kicad_pcb]
2020-06-10 Updated widened display footprint
    Still needs layout adjustments to adapt to the larger footprint and
    moved pin locations.
    [matrix.kicad_pcb, matrix.sch]
2020-06-11 Resize board and place components
    Routing up next.
    [matrix.kicad_pcb]
2020-06-11 Widen capacitor footprint pads
    Easier for hand soldering.
    [matrix.kicad_pcb, matrix.sch]
2020-06-11 Widen resistor pads
    For easier hand soldering.
    [matrix.kicad_pcb, matrix.sch]
2020-06-11 Power net in place
    [matrix.kicad_pcb]
2020-06-11 Wire up LED cathodes
    [matrix.kicad_pcb]
2020-06-14 Wire up most of the layout
    [matrix.kicad_pcb]
2020-06-14 Wire up everything but ground net
    [matrix.kicad_pcb]
2020-06-14 Wire up remaining traces
    [matrix.kicad_pcb]
2020-06-14 Add Open Hardware and KiCad logos
    [matrix.kicad_pcb, matrix.sch]
2020-06-15 Generate Gerbers
    [matrix-B_Cu.gbl, matrix-B_Mask.gbs, matrix-B_SilkS.gbo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]
2020-06-22 Add testing code
    Added a Python, gpiozero-based testing program for Raspberry Pi to
    display test patterns on the matrix display.
2020-07-03 Fix MOSFET symbol pinout
    This fixes the mistake in the MOSFET symbol that incorrectly paired
    up input pins 1-2 with output pins 5-6 and input 3-4 with 7-8.
    Instead, pins 1-2 (source & gate) map to output pins 7-8 (drain) and
    3-4 map to 5-6.
    The result of this mistake in v01 of the board means that every pair
    of display rows are flipped. At a high refresh rate this should not
    be visible, but it does require a workaround in the driver software
    that swaps the contents of every pair of display rows.
    [matrix.kicad_pcb, matrix.sch]
2020-07-03 Add Python requirements for Raspberry Pi code
2020-07-04 Add Arduino firmware
    This adds an Arduino project to drive the display. It uses a timer
    interrupt to refresh the screen at 61Hz while the main loop is
    available for code.
2020-07-04 Cleanup Arduino firmware
2020-07-04 Move row adjustment out of interrupt routine
2020-07-05 Tetris: Add tetromino definitions
    Also implemented basic falling movement and colliding with the
    bottom.
    [arduino.ino]
2020-07-06 Tetris: Add buttons
2020-07-06 Tetris: Fix incorrect J tetromino
    [arduino.ino]
2020-07-06 Tetris: Add press-and-hold for down button
2020-07-06 Tetris: Un-mirror screen and board buffers
2020-07-06 Document MOSFET layout fail
2020-07-08 Tetris: Fix bug in copying board to screen
    Also increased soft-drop speed and lowered global memory usage.
    [arduino.ino]
2020-07-15 Increase refresh rate to 125Hz
2020-07-18 Tetris: Show current + hiscore at end screen
2020-07-26 Tetris: Add pause button
